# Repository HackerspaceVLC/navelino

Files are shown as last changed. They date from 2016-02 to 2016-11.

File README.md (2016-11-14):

# navelino

Arduino custom para Hackerspace Valencia!
* ATMEGA328P-AU
* 3.3V
* 12Mhz

## Bootloader

Usamos una versión especial de optiboot compilada para 12Mhz.
Navelino con el Optiboot es el equivalente a un Arduino Uno

#### Optiboot

https://github.com/Optiboot/optiboot
https://github.com/Optiboot/optiboot/wiki/HowOptibootWorks

### Flashear el Bootloader

##### Buspirate:

Es posible usar el Buspirate como un ISP, hay que seguir las instrucciones del sisguiente enlace para conectar el Buspirate a los pines de ISP ( La versión de Buspirate es importante )

http://dangerousprototypes.com/docs/Bus_Pirate_AVR_Programming
http://dangerousprototypes.com/docs/Bus_Pirate_I/O_Pin_Descriptions
https://antibore.files.wordpress.com/2011/06/buspirate.png

#### Linux & Mac

```
avrdude -c buspirate -P /dev/<device> -p atmega328p -U flash:w:optiboot_atmega328_12.hex -U lfuse:w:0xFF:m -U hfuse:w:0xDE:m -U efuse:w:0x05:m
```

#### Windows

???

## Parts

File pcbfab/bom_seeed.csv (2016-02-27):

Part/Designator | Manufacture Part Number/Seeed SKU | Quantity
CON1 | 320010000 | 1
X0 | 306010047 | 1
IC1 | 310010049 | 1
D10,D5,D8,D4,D9,D7,D6 | 304090046 | 7
D2,D3,D1 | 304090061 | 3
R0 | 301010361 | 1
R1,R2,R3,R4,R5,R6,R7,R8,R9,R10 | 301010364 | 10
C1,C3,C4,C7 | 302010165 | 4
C5,C6 | 302010150 | 2
C2 | 302010179 | 1
U1 | 310030046 | 1
SW0 | 311020047 | 1
SW1,SW2 | 311020004 | 2
P3 | 320020070 | 1

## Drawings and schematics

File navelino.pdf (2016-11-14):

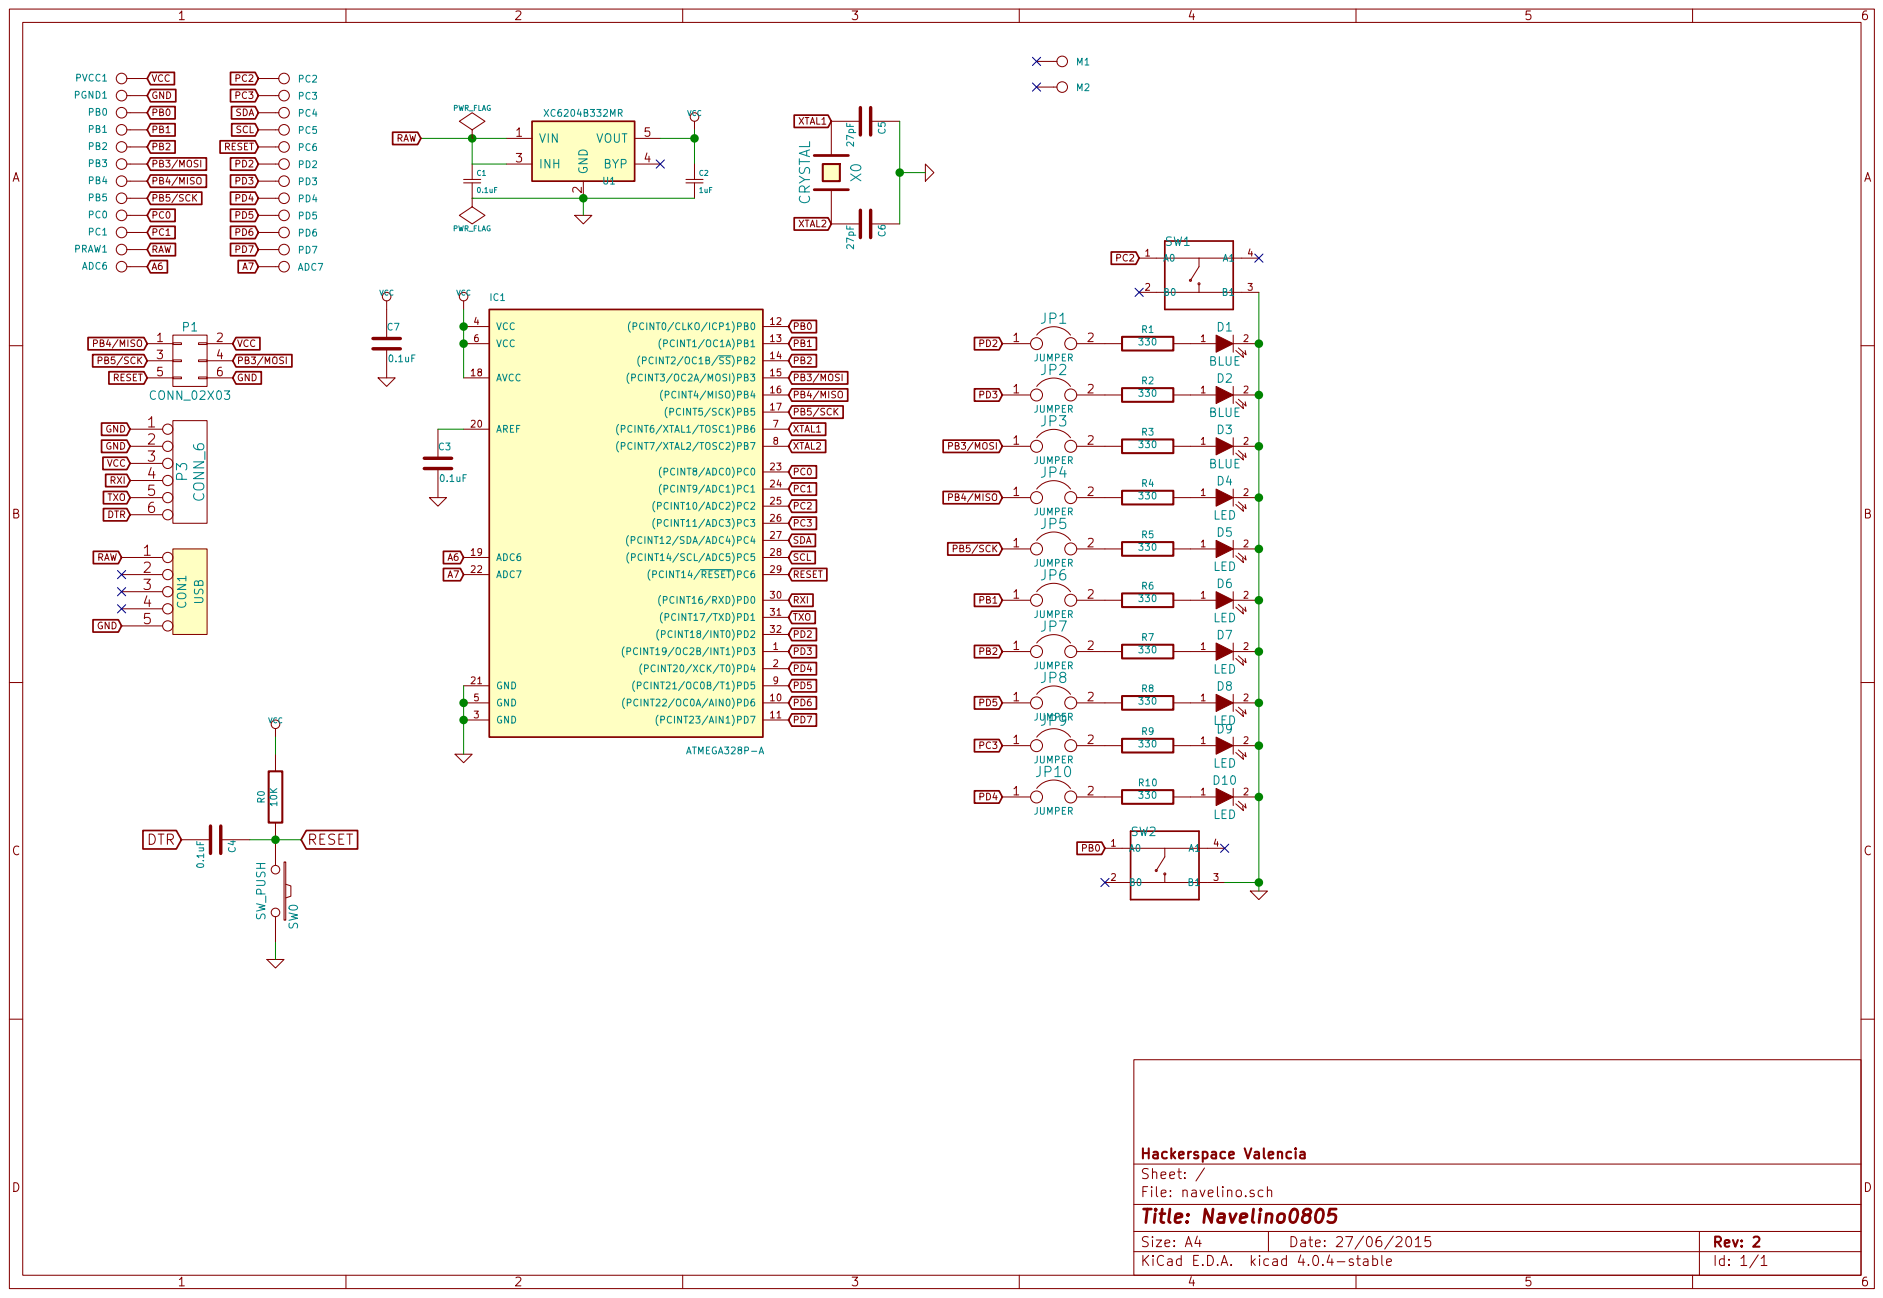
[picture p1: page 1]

File: navelino.sch Sheet: / Hackerspace Valencia

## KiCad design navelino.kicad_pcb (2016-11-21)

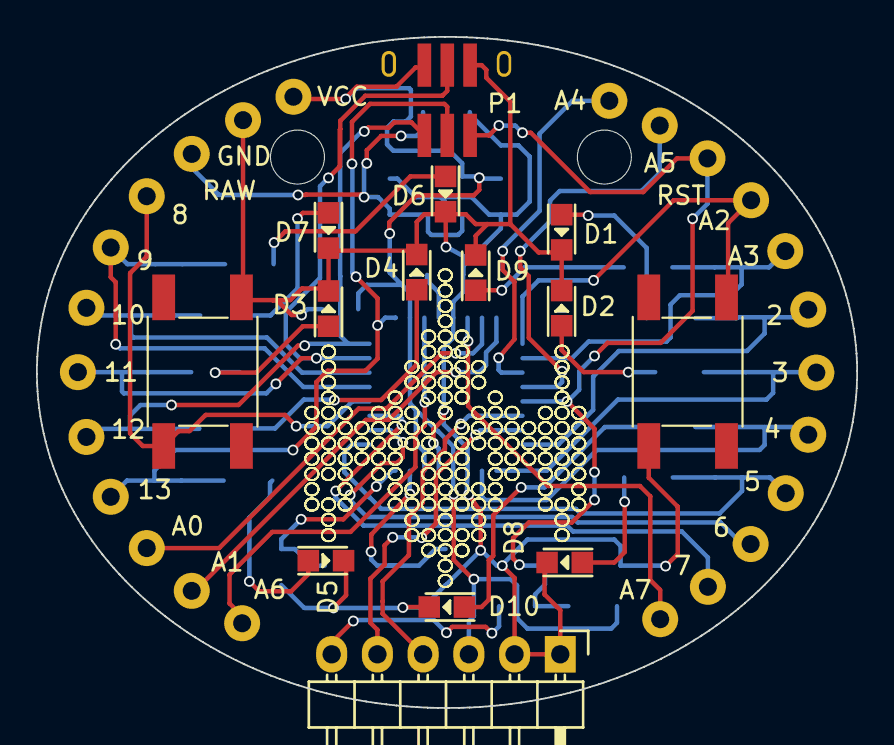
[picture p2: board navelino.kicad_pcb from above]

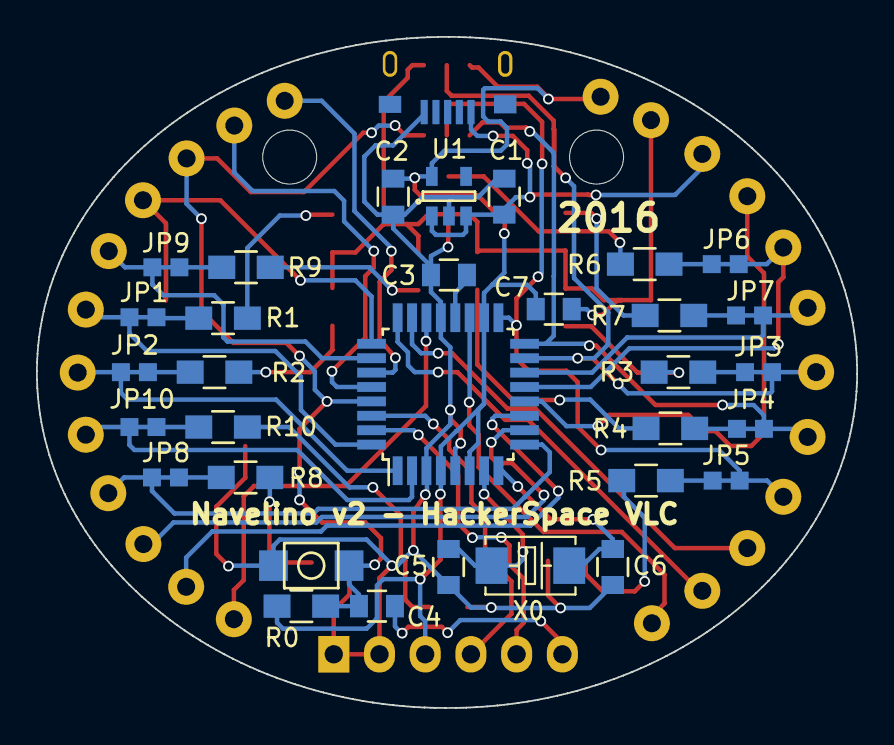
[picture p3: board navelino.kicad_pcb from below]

Board: 2 copper layers, 45.6 x 37.3 mm, 73 parts (33 on the bottom side), 50 nets.

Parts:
2, 3, 4, 5, 6, 7, 8, 9, 10, 11, 12, 13: CONN_1; SolderWirePad_single_1mmDrill
A0, A1, A2, A3, A4, A5, A6, A7: CONN_1; SolderWirePad_single_1mmDrill
C1, C3, C4, C7: 0.1uF; C_0805
C2: 1uF; C_0805
C5, C6: 27pF; C_0805
CON1: USB; ST-USB-001G
D1, D2, D3: BLUE; LED-0805
D4, D5, D6, D7, D8, D9, D10: LED; LED-0805
GND: CONN_1; SolderWirePad_single_1mmDrill
IC1: ATMEGA328P-A; TQFP-32_7x7mm_Pitch0.8mm
JP1, JP2, JP3, JP4, JP5, JP6, JP7, JP8, JP9, JP10: JUMPER; PCB_JUMPER
M1, M2: CONN_1; MountingHole_3mm
P1: CONN_02X03; ISPSMD
P3: CONN_6; Pin_Header_Angled_1x06
R0: 10K; R_0805_HandSoldering
R1, R2, R3, R4, R5, R6, R7, R8, R9, R10: 330; R_0805_HandSoldering
RAW: CONN_1; SolderWirePad_single_1mmDrill
RST: CONN_1; SolderWirePad_single_1mmDrill
SW0: SW_PUSH; B3U-1000P
SW1, SW2: SMD-SWITCH-TACTILE-SPST-NO(4P-D6.0MM); SW4-SMD-6.0X6.0X5.0MM
U1: XC6204B332MR; SOT-23-5
VCC: CONN_1; SolderWirePad_single_1mmDrill
X0: CRYSTAL; X2-SMD-5.0X3.2X1.3MM

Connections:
A6: A6.1, IC1.19
A7: A7.1, IC1.22
DTR: C4.2, P3.6
GND: C1.2, C2.2, C3.2, C5.1, C6.1, C7.2, CON1.5, D1.2, D2.2, D3.2, D4.2, D5.2, D6.2, D7.2, D8.2, D9.2, D10.2, GND.1, IC1.3, IC1.5, IC1.21, P1.6, P3.1, P3.2, SW0.2, SW1.3, SW2.3, U1.2
unnamed: C3.1, IC1.20
unnamed: D1.1, R1.2
unnamed: D2.1, R2.2
unnamed: D3.1, R3.2
unnamed: D4.1, R4.2
unnamed: D5.1, R5.2
unnamed: D6.1, R6.2
unnamed: D7.1, R7.2
unnamed: D8.1, R8.2
unnamed: D9.1, R9.2
unnamed: D10.1, R10.2
unnamed: JP1.2, R1.1
unnamed: JP2.2, R2.1
unnamed: JP3.2, R3.1
unnamed: JP4.2, R4.1
unnamed: JP5.2, R5.1
unnamed: JP6.2, R6.1
unnamed: JP7.2, R7.1
unnamed: JP8.2, R8.1
unnamed: JP9.2, R9.1
unnamed: JP10.2, R10.1
PB0: 8.1, IC1.12, SW2.1
PB1: 9.1, IC1.13, JP6.1
PB2: 10.1, IC1.14, JP7.1
PB3/MOSI: 11.1, IC1.15, JP3.1, P1.4
PB4/MISO: 12.1, IC1.16, JP4.1, P1.1
PB5/SCK: 13.1, IC1.17, JP5.1, P1.3
PC0: A0.1, IC1.23
PC1: A1.1, IC1.24
PC2: A2.1, IC1.25, SW1.1
PC3: A3.1, IC1.26, JP9.1
PD2: 2.1, IC1.32, JP1.1
PD3: 3.1, IC1.1, JP2.1
PD4: 4.1, IC1.2, JP10.1
PD5: 5.1, IC1.9, JP8.1
PD6: 6.1, IC1.10
PD7: 7.1, IC1.11
RAW: C1.1, CON1.1, RAW.1, U1.1, U1.3
RESET: C4.1, IC1.29, P1.5, R0.1, RST.1, SW0.1
RXI: IC1.30, P3.4
SCL: A5.1, IC1.28
SDA: A4.1, IC1.27
TXO: IC1.31, P3.5
VCC: C2.1, C7.1, IC1.4, IC1.6, IC1.18, P1.2, P3.3, R0.2, U1.5, VCC.1
XTAL1: C5.2, IC1.7, X0.1
XTAL2: C6.2, IC1.8, X0.2

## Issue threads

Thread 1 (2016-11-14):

Mejorar el silkscreen de los leds

llunaplanet, 2016-11-14:
La indicación de ánodo / cátodo no se ve bien y no es posible soldar sin comprobar primero con el tester dónde está GND

llunaplanet, 2016-11-21:
Oki esto ya está corregido

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

Closed 2016-11-21.

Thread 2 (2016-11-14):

Añadir plano de masa

llunaplanet, 2016-11-14:
Añadir plano de masa, a parte de que es recomendable, también hará que el Navelino se vea más naranja :)

- Por las dos caras masa @caramono ? O en una cara masa y en la otra VCC?

marchante0, 2016-11-15:
¿Ya estás queriendo hacer condensadores caseros como Pachón?

llunaplanet, 2016-11-17:
@caramono El plano de masa no se rellena del todo, en algunas zonas se podrían poner islas de cobre sin conectar a ninguna NET, eso sería correcto o que?

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

caramono, 2016-11-18:
Si puedes intenta cambiar los parametros del relleno a ver si mejora. Baja el clearance y elimina los thernals, que sea conexion directa a gnd. Asi tambien puede que mejores el plano en el borde de placa (se ve por a3, 2, 3, etc, que no se junta del todo), y conseguir que bordee todo el lado de raw, 8,9,etc.

Si asi no mejora, intenta poner vias de top a bot, de gnd a gnd, conectando las islas sueltas.
No pasa nada si estan sueltas, pero mejor si estan conectadas.

caramono, 2017-01-17:
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
Con clearance 0.25, min width 0.25, fill mode polygon, outline style fully hatched.

Segun pcbway, aguantan clearance de 0.15 con la opcion mas barata, Perfecto!

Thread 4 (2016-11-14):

Convertir los pines en "Castellated Holes"

llunaplanet, 2016-11-14:
No es muy sencillo flashear sin soldar a los pines ISP, sería interesante hacer los pines de los bordes "castellated" para eso hay que ver si PCBWAY lo permite.

caramono, 2017-01-17:
No se... igual dejarlos como pads sueltos para programarlo 1 vez. No creo que se use muchas veces, la mayoria usaremos la hoja "para diario".

Los cassellated para los pines normales, no te digo yo que no. Son una buena opcion para soldar permanentemente a una placa.

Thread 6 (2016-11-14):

Investigar tema de licencias para OSHW

llunaplanet, 2016-11-14:

marchante0, 2016-11-15:
En resumen:

- [ ] Buscar si fuera necesario por parte de Atmel.
- [ ] Buscar si fuera necesario por parte del Bootloader.

llunaplanet, 2016-11-17:
@marchante0 He visto el el driver USB de la hoja usa una GNU GPL v2

https://github.com/obdev/v-usb/blob/master/usbdrv/License.txt

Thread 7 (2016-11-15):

¿Un zip en un repositiorio?

marchante0, 2016-11-15:
Hay un zip con demasiada basura tipo DS_store para el cual no veo razón de ser un zip ni estar lleno de basura **(también tiene el blob .hex que debería tener)**.

llunaplanet, 2016-11-17:
Eso es un zip, para poder meter en Arduino la definición de la placa, lo limpiaré de basurillas de MAC :)

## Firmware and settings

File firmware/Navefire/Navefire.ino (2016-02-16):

int blink_speed = 250;
int blink_pause = 1000;

int pushButtonD = 16; // PC2
int pushButtonI = 8; // PB0

// the setup function runs once when you press reset or power the board
void setup() {

  Serial.begin(9600);
  pinMode(pushButtonD, INPUT_PULLUP); // Enable pullup
  pinMode(pushButtonI, INPUT_PULLUP); // Enable pullup

  // initialize digital pin 13 as an output.
  pinMode(12, OUTPUT); // D4
  pinMode(3, OUTPUT); // D2
  pinMode(2, OUTPUT); // D1
  pinMode(17, OUTPUT); // D9
  pinMode(11, OUTPUT); // D3
  pinMode(10, OUTPUT); // D7
  pinMode(9, OUTPUT); // D6
  pinMode(13, OUTPUT); // Azul izquierda D5
  pinMode(5, OUTPUT); // Azul derecha
  pinMode(4, OUTPUT); // Azul centro

  self_test(blink_speed);

}

// the loop function runs over and over again forever
void loop() {

  self_test(blink_speed);

  // read the input pin:
  int buttonStateI = digitalRead(pushButtonI);
  int buttonStateD = digitalRead(pushButtonD);
  
  if (buttonStateD == 0) {
    blink_speed -= 50;
    blink_pause -= 150;
  }
  if (blink_speed <= 0) blink_speed = 50;
  if (blink_pause <= 0) blink_pause = 150;
  

  if (buttonStateI == 0) {
    blink_speed += 50;
    blink_pause += 150;
  }
  
  if (blink_speed >= 1000) blink_speed = 1000;
  if (blink_pause >= 2000) blink_pause = 2000;
  
  // print out the state of the button:
  Serial.print(buttonStateI);
  Serial.print(" ");
  Serial.println(buttonStateD);
  
  delay(1);        // delay in between reads for stability


}

void self_test(int speed) {
  digitalWrite(9, HIGH);
  delay(speed);
  digitalWrite(9, LOW);

  digitalWrite(12, HIGH);
  digitalWrite(17, HIGH);
  delay(speed);
  digitalWrite(12, LOW);
  digitalWrite(17, LOW);

  digitalWrite(10, HIGH);
  digitalWrite(2, HIGH);
  delay(speed);
  digitalWrite(10, LOW);
  digitalWrite(2, LOW);

  digitalWrite(11, HIGH);
  digitalWrite(3, HIGH);
  delay(speed);
  digitalWrite(11, LOW);
  digitalWrite(3, LOW);

  digitalWrite(13, HIGH);
  digitalWrite(5, HIGH);
  delay(speed);
  digitalWrite(13, LOW);
  digitalWrite(5, LOW);

  digitalWrite(4, HIGH);
  delay(speed);
  digitalWrite(4, LOW);

  delay(blink_pause);

}

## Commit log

2015-06-27 Import inicial
    [navelino.kicad_pcb, navelino.sch]
2015-06-28 Actualizado el regulador a algo más pequeño :)
    [navelino.kicad_pcb, navelino.sch]
2015-10-13 Cambiados casi todos los componentes de 06 a 08 para que pueda funcionar como taller de soldadura SMD Añadido el Jumper para poder desactivar los leds y usar los pines libremente
    [navelino.kicad_pcb, navelino.sch]
2015-12-15 Finalizado el routing!
    [navelino.kicad_pcb, navelino.sch]
2015-12-18 Un poco de amor para el Silkscreen
    [navelino.kicad_pcb, navelino.sch]
2015-12-18 Cambios de algunas referencias de seeed
2015-12-21 Condensadores de X0 cambiados a 27pF Añadidos orificios de montaje de 3mm
    [navelino.kicad_pcb, navelino.sch]
2015-12-21 Pequeños ajustes antes de generar el gerber
    [navelino.kicad_pcb]
2015-12-21 Versión con los Jumpers de los leds cerrados
    [navelino.kicad_pcb]
2016-02-15 Intercambio TX/RX
    [navelino.sch]
2016-02-15 Intercambio RX/TX Conexión GND que faltaba en etapa de alimentación
    [navelino.kicad_pcb]
2016-02-16 Versión inicial de Navefire, prueba de leds / botones, etc
2016-02-16 boards.txt para poder programar desde Arduino
2016-02-27 Upssss, carga de librerías, BOM para SEED, y ZIP
    [bom_seeed.csv]
2016-10-25 Empezando a meter las dependencias de librerías dentro del proyecto Substituido el conector de la hoja por algo más standard
    [navelino.kicad_pcb, navelino.sch]
2016-11-14 Archivos de fabricación de la v2
    [navelino-B.Cu.gbl, navelino-B.Mask.gbs, navelino-B.SilkS.gbo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]
2016-11-14 Añadir información para cargar el bootloader desde buspirate
2016-11-14 Actualizar rev2 en el pdf
    [bom_seeed.csv, navelino.sch]
2016-11-14 Añadido bootloader Optiboot compilado para 12Mhz
    [navelino.kicad_pcb]
2016-11-21 Corregida la huella de los LEDs 0805, el cátodo ya está donde toca :)
    [navelino.kicad_pcb]
